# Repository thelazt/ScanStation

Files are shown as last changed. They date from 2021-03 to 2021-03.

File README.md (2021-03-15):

ScanStation
===========

Nach einem langen Arbeitstag zu Hause angekommen, gibt es nur bedingt Motivation neue, archivierungsrelevante Briefe in den entsprechenden Ordner einzusortieren.
Wenn dann die Zeit da ist sich um diese Dokumente mal zu kümmern, sind diese oftmals nicht direkt greifbar.
Und wenn dann mal ein konkreter Brief gesucht wird, ist das selbst bei ordentlicher Sortierung eine umständliche Arbeit.

Abhilfe würde eine einfache und bequeme Digitalisierung schaffen, während die Originaldokumente dann (somit auch automatisch chronologisch geordnet) in eine Archivbox wandern.

Da der Start eines üblichen Heim-PCs zum Digitalisieren jedoch nicht zwingend *bequem* ist, wird hier eine andere Lösung präferiert, welche autonom arbeitet.

Außerdem soll hierfür primär alte oder zumindest günstige Hardware zum Einsatz kommen:
Ein alter Scanner (bzw. Multifunktionsdrucker) findet sich noch in vielen Haushalten, die Steuerung übernimmt ein [Raspberry Pi](https://de.wikipedia.org/wiki/Raspberry_Pi), welcher lediglich über ein paar Taster und eine kleine OLED Anzeige (Kostenpunkt Peripherie: etwa 5 Euro) gesteuert werden kann.

Selbstverständlich soll nur freie Software eingesetzt werden (sofern möglich, potenzielle Ausnahme: proprietäre Scannertreiber ohne freie Alternativen).

Ablauf
------

Flussdiagramm

Die neu eingegangenen Papier-Dokumente werden über einen an die **ScanStation** angeschlossenen Scanner durch einen einzigen Tastendruck digitalisiert, komprimiert, eine Texterkennung durchgeführt und mittels Versionsverwaltung digital archiviert.

Das Originaldokument kommt nach dem [FIFO-Verfahren](https://de.wikipedia.org/wiki/First_In_%E2%80%93_First_Out) in eine Archivbox, je nach Postaufkommen wird im Monats-, Quartals- oder Jahrestakt entweder ein Trennblatt eingefügt oder die volle Box beschriftet, auf den Dachboden verfrachtet und durch eine neue, leere Box beim Scanner ersetzt.

Durch die verteilte Versionsverwaltung [git](https://de.wikipedia.org/wiki/Git) können die Dokumente von beliebigen berechtigten Systemen gelesen werden.
Obwohl für den Zugriff aufgrund der einfachen Ordnerstruktur (Name entspricht dem Datum) und der Archivierung als [PDF](https://de.wikipedia.org/wiki/Portable_Document_Format) nur die übliche Standardsoftware benötigt wird, ist das erstellte Ordner- und Dateiformat für die Software [Paperwork](https://openpaper.work/) (für Linux & Windows) optimiert:
Sie bietet über eine grafische Oberfläche (und auch via Kommandozeileneingabe) eine chronologisch geordnete Übersicht aller Dokumenteneingänge, eine einfache Suche über die per Texterkennung extrahierten Inhalte sowie die Möglichkeit die Dokumente mittels Annotierungen weiter einzuordnen -- diese können (und sollen) natürlich wieder in das Versionsverwaltungssystem übertragen werden.

Bedienung
---------

Benutzerschnittstelle

Die gesamte Benutzerschnittstelle besteht aus vier Tasten und einem kleinen, niedrig auflösenden Monochromdisplay.

Die durch kleine Piktogramme bebilderten Funktionen der Tasten sind:
 * Ein neues Dokument (Seite 1) scannen
 * Eine weitere Seite zum aktuellen Dokument hinzufügen
 * Die zuletzt gescannte Seite im Speicher löschen (dokumentenübergreifend, Stack-Prinzip)
 * Fertig / Komprimierung, Texterkennung und Synchronisierung (in das entfernte Versionsverwaltungssystem) starten

Das Display zeigt den aktuellen Zustand des Systems und während des Scans den aktuellen Fortschritt (mit Miniaturvorschau) an.

Aufbau
------

Es werden folgende Hardwarekomponenten benötigt:

 * [SANE-kompatibler](http://www.sane-project.org/sane-supported-devices.html) USB-Scanner
 * Rasperry Pi (2/3/4)
 * 4 Taster
 * monochromes I²C OLED Display ([SSD1306](https://cdn-shop.adafruit.com/datasheets/SSD1306.pdf))
 * *optional:* Speicherplatz auf Server für Dokumentenarchiv
 * *optional:* Zugriff auf Laser-Cutter sowie ein paar HDF für Gehäuse

Die Verkabelung und der Aufbau wird in der [Bauanleitung](BUILD.md) erklärt.

Dieses Projekt bündelt vor allem vorhandene Lösungen (insbesondere von [OpenPaperwork](https://gitlab.gnome.org/World/OpenPaperwork)) und stellt ein einfaches Benutzerinterface dafür bereit, konkret baut es dabei auf folgender Software auf:

 * dem debianoiden [Raspbian](https://www.raspberrypi.org/software/operating-systems/) als Betriebssystem
 * Python 3 mit Grafikbibliotheken ([Pillow](https://pillow.readthedocs.io/en/latest/), [Cairo](https://pycairo.readthedocs.io/en/latest/) usw.)
 * [Sane](http://www.sane-project.org/) Werkzeuge (sowie [Libinsane](https://gitlab.gnome.org/World/OpenPaperwork/libinsane))
 * [JBIG2 Encoder](https://github.com/agl/jbig2enc)
 * sowie [Paperwork](https://openpaper.work/) für die Verwaltung der Dokumente

Weitere Details dazu finden sich in der [Installationsanleitung](INSTALL.md).

Designentscheidungen
--------------------

### Minimalistische Benutzerschnittstelle

Die Verwendung von nur vier Tasten sowie ein kleines Monochromdisplay sorgt nicht nur für eine einfache Bedienung, sondern auch die Entwicklung der Software ist deutlich einfacher (und die Hardware günstiger!) als z. B. mit einem kleinen Touchpad.
Außerdem würde eine solche Toucheingabe schlicht keinen Mehrwert für das System bringen.

### Versionsverwaltungssystem

Da die PDF-Dokumente nur die Bilddateien als Inhalt haben (die Resultate der Texterkennung werden in einer separaten Datei im XML Format gespeichert) und nach der Erstellung nicht mehr bearbeitet werden, kann *git* diese gut verwalten.
Alle Änderungen (wie Annotationen) geschehen nur in zusätzlichen Textdateien, Dateisystemoperationen wie die Umbenennung des Ordners (in Paperwork automatisch bei Änderung des Datums) werden von diesem Versionsverwaltungssystem gut erkannt und nur durch Änderungen der Metadaten gespeichert. Aus Archivierungssicht ist auch eine lückenlose Nachvollziehbarkeit von Änderungen -- ohne Möglichkeit diese unerkannt zu modifizieren -- wünschenswert. Zudem können bequem Spiegelungen des Repositorys erstellt werden.

### JBIG2 Bildformat

Mit dem [JBIG2](https://de.wikipedia.org/wiki/JBIG2)-Format können sehr gute Kompressionsraten erzielt werden: Eine typische Din-A4 Seite braucht bei 600 DPI im Schnitt nur zwischen 25KB und 50KB.

Leider kommt dies mit einigen signifikanten Nachteilen:
Zum einen wird nur Schwarz-Weiß (keine Graustufen!) unterstützt, zum anderen gibt es durch die verlustbehaftete Komprimierung die Gefahr, dass Zeichen *vertauscht* werden (im schlimmsten Fall wird eine *6* zu einer *8*, siehe Vortrag [Traue keinem Scan, den du nicht selbst gefälscht hast](http://www.dkriesel.com/blog/2013/0802_xerox-workcentres_are_switching_written_numbers_when_scanning)).

Wieso dennoch dieses Format verwenden?
 * Die Kompressionsraten von anderen Verfahren, welche nicht an diesem Problem leiden (wie [JPEG 2000](https://de.wikipedia.org/wiki/JPEG_2000)) sind leider deutlich schlechter, was sich auf längere Sicht auch in einem deutlich zu hohen Speicherbedarf niederschlagen wird. Daneben gibt es mit der Texterkennung auch einen weiteren Faktor für Fehler bei der Zeichenerkennung -- weshalb auch die Suchergebnisse mit einer gewissen Skepsis betrachtet werden müssen.
 * Da eigentlich nur textuelle Dokumente relevant für die Archivierung sind, ist das Fehlen von Farben oder Graustufen in der digitalisierten Form kein Nachteil.
 * Bilder können in diesem Format in PDF-Dateien eingebettet werden, d.h. es ist keine spezielle Software zum Betrachten notwendig.

Schlussendlich sollen diese digitalisierten Dokumente nicht die Originaldokumente ersetzen, sondern nur den Zugriff auf diese vereinfachen: Die digitalen Versionen sind überall verfügbar und können einfach durchsucht werden, bei Bedarf erlauben sie (durch das Datum) einen einfachen Zugriff auf die tatsächlichen Papierdokumente.

Beispiel
--------

Die *ScanStation* im Praxisbetrieb:

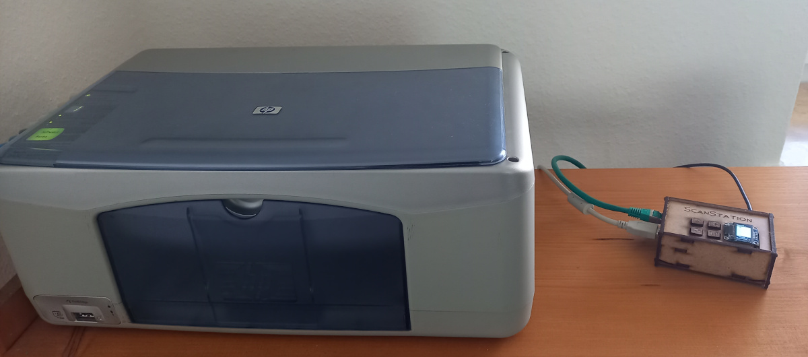
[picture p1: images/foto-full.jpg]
Foto Überblick


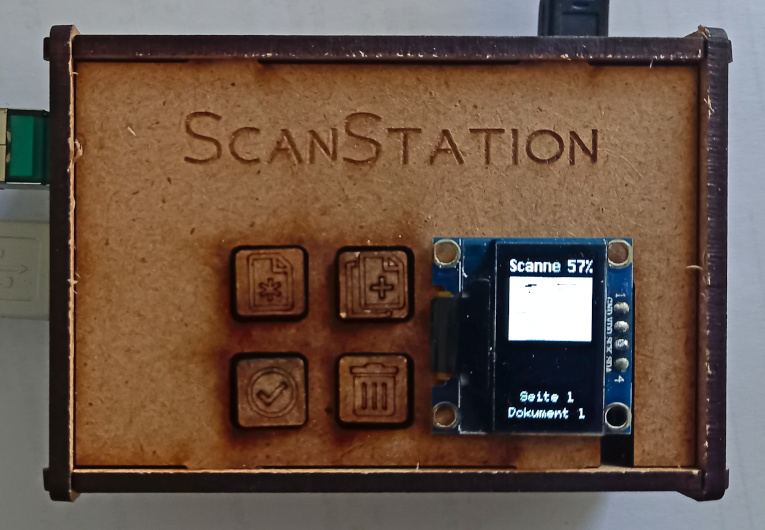
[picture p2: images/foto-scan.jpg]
Foto Scan


Weiterentwicklung & Lizenz
--------------------------

Da die hier präsentierte *ScanStation* erfolgreich im Einsatz ist und die geforderte Funktionalität bietet, darf dieses Projekt als abgeschlossen betrachtet werden -- eine Weiterentwicklung meinerseits ist nicht geplant (zumindest so lange ich keine neue Funktionalität brauche).

Die Skripte und Vorlagen dürfen jedoch gerne weiterverwendet und an die eigenen Bedürfnisse angepasst werden, sie stehen unter der [GNU AGPL v3](LICENSE.md).

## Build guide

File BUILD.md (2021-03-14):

Raspberry Pi Hardware
=====================

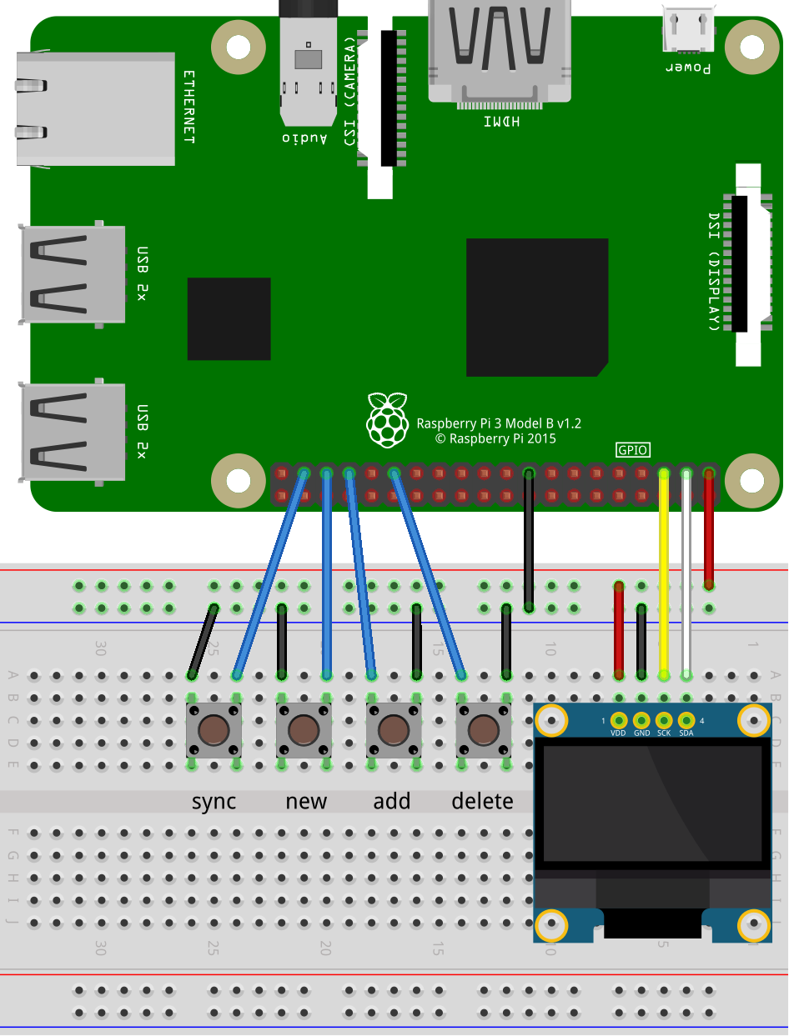
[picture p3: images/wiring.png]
Flussdiagramm


Mit Lötkolben und Lochplatine bewaffnet kann man (ohne größere Fähigkeiten) einen HAT für den Raspberry Pi basteln, für die Verkabelung der Tasten bieten sich
 * *GPIO5* (Pin 29)
 * *GPIO13* (Pin 33)
 * *GPIO19* (Pin 35)
 * *GPIO26* (Pin 37)
 * sowie *GND* auf Pin 25 und 39 an

Das [SSD1306](https://cdn-shop.adafruit.com/datasheets/SSD1306.pdf)-Display wird über [I²C](https://de.wikipedia.org/wiki/I%C2%B2C) angesteuert und sollte daher
 * *GPIO2* (Pin 3) für Datenleitung (SDA)
 * *GPIO3* (Pin 5) für Taktleitung (SCL) sowie
 * *3V3* (Pin 1) für Versorgungsspannung (VCC) und
 * *GND* auf Pin 6 oder 9 für die Masse

Die Position der Taster sollte natürlich zum Gehäuse passen.

Ein Beispielplan für ein 3mm-[HDF](https://de.wikipedia.org/wiki/Harte_Faserplatte)-Gehäuse mittels Lasercutter (zu finden im nächsten Maker-Space oder [FabLab](https://de.wikipedia.org/wiki/FabLab)):

Laser-Cut-Plan

Es bietet sich ggf. an die Tasten selbst aus dickeren (5mm) Platten zu lasern:

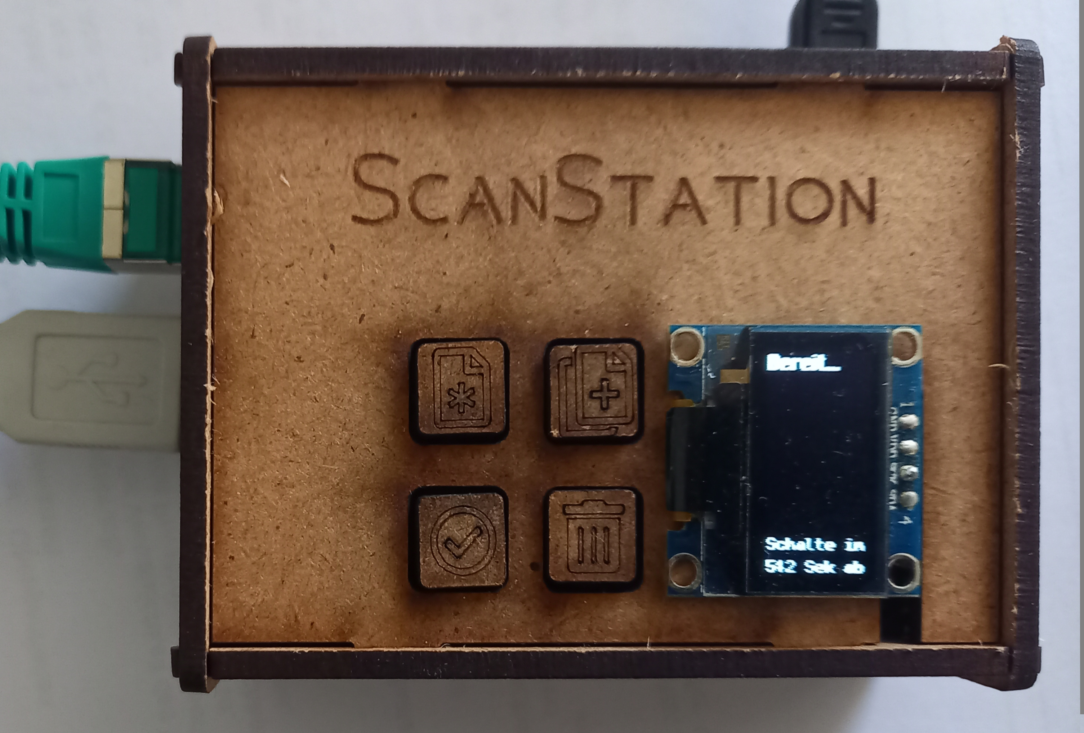
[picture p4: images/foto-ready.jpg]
Foto


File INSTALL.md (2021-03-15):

Raspberry Pi Software
=====================

Auf eine SD-Karte ein [Raspbian](https://www.raspberrypi.org/software/operating-systems/) (Lite -- ohne Desktop) kopieren und den *Raspberry Pi* booten.

Nach dem Anmelden muss via `sudo raspi-config` in *3 Interface Options* unter *P5 I2C* das I²C Kernelmodul aktiviert werden (wird für das Display gebraucht).

Danach müssen die benötigten Pakete für die *ScanStation* (Eingabe via GPIO, Ausgabe via OLED-Display & Scannersteuerung) installiert & natürlich dieses Repo lokal geklont werden:

	sudo apt update
	sudo apt dist-upgrade
	sudo apt install git python3 python3-pip python3-pil libgirepository1.0-dev libcairo2-dev pkg-config python3-dev gir1.2-gtk-3.0 rpi.gpio 

	python3 -m pip install --upgrade pip
	python3 -m pip install pycairo PyGObject luma.oled luma.core

	git clone --recursive https://github.com/thelazt/scanstation.git ~/scanstation

Scanner
-------

Es kann jeder [SANE](https://de.wikipedia.org/wiki/Scanner_Access_Now_Easy)-kompatible Scanner verwendet werden.
Für einen (alten) HP OfficeJet braucht man beispielsweise das Paket `hplip`:

	sudo apt install hplip

	sudo sane-find-scanner
	sudo scanimage -L

	sudo usermod -a -G scanner pi

Sofern `scanimage -L` ohne `sudo` keine Ergebnisse liefert, müssen noch die udev-Regeln angepasst werden. Dazu beispielsweise via `lsusb` für den USB Scanner *HP PSC 1315*

	Bus 001 Device 004: ID 03f0:3f11 HP, Inc PSC-1315/PSC-1317

die Vendor- (hier `03f0`) und Product-ID (`3f11`) herausfinden und eine entsprechende neue Regel erstellen:

	echo 'ATTRS{idVendor}=="03f0", ATTRS{idProduct}=="3f11",  MODE="0666", GROUP="scanner", ENV{libsane_matched}="yes"' > /etc/udev/rules.d/99-libsane.rules
	sudo udevadm control --reload-rules
	sudo udevadm trigger

JBIG2 Encoder
-------------

Die eingescannten Seiten werden im [Portable Document Format (PDF)](https://de.wikipedia.org/wiki/Portable_Document_Format) gespeichert, bei welchem die gescannten Bilder für eine geringe Dateigröße wiederum im [JBIG2](https://de.wikipedia.org/wiki/JBIG2)-Format gespeichert werden.

	sudo apt install autoconf gcc make libtool libleptonica-dev
	cd jbig2enc
	./autogen.sh
	./configure
	make -j 4
	cd ..

libinsane
---------

Die Bibliothek [Libinsane](https://gitlab.gnome.org/World/OpenPaperwork/libinsane) bietet für die Skriptsprache Python einen einfachen Zugriff auf angeschlossene Scanner.
Dafür werden noch einige Buildwerkzeuge und Programmbibliotheken benötigt, es kann wie folgt installiert werden:

	sudo apt install meson cmake libsane-dev gtk-doc-tools valac
	cd libsane
	make
	sudo make install
	cd ..

Paperwork
---------

Für die Verwaltung der Dokumente wird [Paperwork](https://openpaper.work/) verwendet. Das kann über den [Python Paketmanager (pip)](https://de.wikipedia.org/wiki/Pip_(Python)) installiert werden, dazu wird aber die PDF Programmbibliothek [Poppler](https://de.wikipedia.org/wiki/Poppler) sowie die [Texterkennungssoftware (OCR)](https://de.wikipedia.org/wiki/Texterkennung) [Tesseract](https://de.wikipedia.org/wiki/Tesseract_(Software)) benötigt:

	sudo apt install poppler-data libpoppler-dev libpoppler-cpp-dev gir1.2-poppler-0.18 iso-codes tesseract-ocr tesseract-ocr-deu 
	python3 -m pip install paperwork paperwork-shell python-poppler termcolor natsort levenshtein

Die Dokumente (als PDF sowie eine XML Datei mit den OCR Daten) werden von *Paperwork* in das Verzeichnis `~/papers/` importiert.
Dieses Verzeichnis sollte natürlich aufgrund der eher kurzen Lebensdauer von SD-Karten irgendwie gesichert werden.
Sofern ein Netzlaufwerk existiert, kann beispielsweise dieses verwendet werden.

Allerdings ist es auch möglich ein [Git-Repository](https://de.wikipedia.org/wiki/Git) zu verwenden:
Die Binärdateien (Bild im PDF Dokument) haben eine akzeptable Größe und werden i.d.R. nicht mehr verändert, entsprechend ist dieses Versionsverwaltungssystem geeignet:

### Repo auf entfernten Server

Auf einem via SSH erreichbaren Server wird nun ein Git Repository angelegt:

	mkdir papers.git
	cd papers.git
	git init --bare

Natürlich können auch andere Git-Hostingplattformen verwendet werden.

### Repoverzeichnis auf RPi

Zuerst sollte ein SSH Schlüssel erstellt und auf den Server authorisiert werden:

	ssh-keygen
	ssh-copy-id user@example.org

Dann wird das eben erstellte Repo auf den Raspberry Pi geklont:

	git clone ssh://user@example.org:/home/user/papers.git /home/pi/papers
	git config --global user.email "scanstation@example.org"
	git config --global user.name "ScanStation"

### Repoverzeichnis auf Arbeitsrechner

Analog dazu kann auf den PCs, mit welchen diese Dokumente angeschaut (und annotiert) werden sollen, das Repo ebenfalls nach `~/papers` geklont werden. Außerdem empfiehlt es sich hier, [Paperwork gemäß der Anleitung zu installieren](https://gitlab.gnome.org/World/OpenPaperwork/paperwork/#installation) -- bei Linux z.B. via 

	git clone ssh://user@example.org:/home/user/papers.git ~/papers
	echo "*.thumb.jpg" > ~/papers/.gitignore
	flatpak --user install https://builder.openpaper.work/paperwork_master.flatpakref

Vor dem Starten sollten Änderungen (via `git pull`) geholt und nach dem Bearbeiten auf den Arbeitsrechnern natürlich immer wieder zurück geschoben (`git push`) werden - dazu kann auch das Hilfsskript `utils/paperwork.sh` verwendet werden.

Konfiguration
-------------

Die Beispielkonfiguration muss nach `config.ini` kopiert und an die eigenen Bedürfnisse angepasst werden:

	cp config.example.ini config.ini
	nano config.ini

(Auto)Start
-----------

Die Python-Skripte werden via [systemd](https://de.wikipedia.org/wiki/Systemd) gestartet, dazu müssen ggf. die Pfade in der `scanstation.service`-Datei angepasst und diese in das Verzeichnis `/etc/systemd/system/` kopiert werden:

	sudo cp scanstation.service /etc/systemd/system/
	sudo systemctl daemon-reload
	sudo systemctl start scanstation

Die *ScanStation* soll nun auch direkt nach dem Boot automatisch gestartet werden, dazu

	sudo systemctl enable scanstation

ausführen.

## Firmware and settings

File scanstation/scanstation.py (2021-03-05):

#!/usr/bin/env python3
# coding=utf-8

import os
import sys
import logging
import subprocess
import tempfile
from pathlib import Path
from datetime import datetime
from enum import Enum
from time import sleep
from configparser import ConfigParser
from PIL import ImageFont, Image


from scanstation.input import Input
from scanstation.output import Output
from scanstation.scanner import Scanner


class ScanStation(object):
    def __init__(self, configfile):
        if not Path(configfile).is_file():
            logging.error('Config file "{}" not found!'.format(configfile))
            sys.exit(1)

        self.config = ConfigParser()
        self.config.read(configfile)

        buttons = {}
        for (key, val) in self.config.items('input'):
            buttons[key.upper()] = int(val)
        self.input = Input(buttons)

        self.oled = Output(ssd1306address = int(self.config.get('display', 'address', fallback='0x3c'), 16), threshold = self.config.getint('display', 'threshold', fallback=210), rotation = self.config.getint('display', 'rotate', fallback=3))

        self.font = ImageFont.truetype(self.config.get('display', 'font_name'), self.config.getint('display', 'font_size'))
        self.fontSmall = ImageFont.truetype(self.config.get('display', 'font_small_name'), self.config.getint('display', 'font_small_size'))

        self.scanner = Scanner(dev_id = self.config.get('scanner', 'device', fallback=None), source_name = self.config.get('scanner', 'source', fallback=None))
        for (key, val) in self.config.items('scanner'):
            if key != 'device' and key != 'source' and key != 'chunk_size':
                logging.info('Setting scannner option "{}" to "{}"...'.format(key, val))
                self.scanner.set(key, val)

        if self.config.has_option('process', 'startup'):
            self.display(title = "Starte\nScanStation")
            self.execute(self.config.get('process', 'startup'))


    def execute(self, cmd):
        process = subprocess.Popen(cmd, stdout=subprocess.PIPE, stderr=subprocess.STDOUT, shell=True)
        logging.debug('Run "{}" as PID {}'.format(cmd, process.pid))

        while process.poll() is None:
            while True:
                output = process.stdout.readline().decode()
                if output:
                    logging.debug('PID {}: {}'.format(process.pid, output))
                else:
                    break
        if process.returncode != 0:
            logging.error('Command "{}" (PID {}) failed with exit code {}'.format(cmd, process.pid, process.returncode))
            sys.exit(process.returncode)


    def display(self, title = None, scan = None, footer = None):
        self.oled.clear()

        if scan:
            self.oled.image(scan, (0, 16))

        draw = self.oled.draw()
        if title:
            draw.text((0, 0), text=title, font=self.font, fill="white")

        if footer:
            draw.text((0, 106), text=footer,  font=self.fontSmall, fill="white", align = "center")

        self.oled.show()


    def scanHelper(self, status):
        return self.scanner.scan(abort = lambda: self.input.pressed(self.input.Button.DELETE), status = status, status_refresh = self.config.getint('scanner', 'status_refresh', fallback=5), max_page = self.config.getint('scanner', 'max_page', fallback=20), chunk_size = self.config.getint('scanner', 'chunk_size', fallback=1024 * 1024))


    def scanImages(self, timeout):
        docs = []
        b = self.input.Button.NEW
        while b and b != self.input.Button.SYNC:
            if b == self.input.Button.NEW or (b == self.input.Button.ADD and len(docs) == 0):
                logging.info('Scanning new document {}...'.format(1 + len(docs)))
                pages = self.scanHelper(lambda page, status, img: self.display(title = "Scanne" + status, scan = img, footer = "Seite " + str(1 + page) + "\nDokument " + str(len(docs) + 1)) )
                if pages and len(pages) > 0:
                    docs.append(pages)
                elif len(docs) == 0:
                    break

            elif b == self.input.Button.ADD:
                d = len(docs)
                logging.info('Scanning additional page of document {}'.format(d))
                pages = self.scanHelper(lambda page, status, img: self.display(title = "Scanne" + status, scan = img, footer = "Seite " + str(len(docs[d - 1]) + 1 + page) + "\nDokument " + str(d)) )
                if pages and len(pages) > 0:
                    docs[d - 1].extend(pages)

            elif b == self.input.Button.DELETE:
                d = len(docs)
                if d == 0 or (d == 1 and len(docs[0]) == 1):
                    del docs[:]
                    return []
                if len(docs[d - 1]) == 1:
                    logging.info('Deleting document {}'.format(d))
                    del docs[-1]
                else:
                    logging.info('Deleting page of document {}'.format(d))
                    del docs[d - 1][-1]

            d = len(docs)
            p = len(docs[d - 1])
            self.display(title = 'Bereit...', scan = docs[d - 1][p - 1], footer = "Seite " + str(p) + "\nDokument " + str(d))
            logging.info('Ready to scan additional page / document!')

            b = self.input.wait(timeout)

        return docs


    def generatePDFs(self, docs, prefix):
        files = []

        with tempfile.TemporaryDirectory() as tmpdirname:
            for idx, doc in enumerate(docs):
                self.display(title = "Erstelle\nDokumente", footer = "PDF " + str(idx + 1) + " / " + str(len(docs)))
                pages = []
                for page, scan in enumerate(doc):
                    logging.info('Exporting page {} of document {} as image...'.format(page + 1, idx + 1))
                    pages.append(tmpdirname + '/image-' + str(idx) + '-' + str(page)  + '.png')
                    scan.save(pages[-1], format='png')

                logging.info('Creating PDF for document {}...'.format(idx + 1))
                files.append(prefix + str(idx) + '.pdf')
                self.execute(self.config.get('process', 'generate').format(images=' '.join(pages), pdf=files[-1]))

        return files


    def importPDFs(self, pdfs):
        for idx, pdf in enumerate(pdfs):
            logging.info('Importing PDF document {}...'.format(idx + 1))
            self.display(title = "PaperWork\nImport...", footer = "PDF " + str(idx + 1) + " / " + str(len(pdfs)))
            self.execute(self.config.get('process', 'import').format(pdf=pdf, index=idx))
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

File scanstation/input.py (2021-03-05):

#!/usr/bin/env python3
# coding=utf-8

import logging
from enum import Enum
from time import sleep
import RPi.GPIO as GPIO


class Input(object):
    wait_time = 0.1
    down = {}


    def event(self, channel):
        self.down[channel] = True


    def pressed(self, button):
        if button.value in self.down and self.down[button.value]:
            self.down[button.value] = False
            return True
        else:
            return False


    def wait(self, timeout=None):
        total = 0
        while not timeout or total < timeout:
           for button in self.Button:
              if self.pressed(button):
                  return button
           sleep(self.wait_time)
           total = total + self.wait_time
        return None


    def __init__(self, buttons):
        self.Button = Enum('Button', buttons, module='input')

        GPIO.setmode(GPIO.BCM)
        for button in self.Button:
            pin = button.value
            GPIO.setup(pin, GPIO.IN, pull_up_down=GPIO.PUD_UP)
            GPIO.add_event_detect(pin, GPIO.FALLING, callback=self.event, bouncetime=300)
            logging.debug("Button {} connected with GPIO {}".format(button.name, pin))


    def  __del__(self):
       GPIO.cleanup()
       logging.debug("GPIO cleaned up")
